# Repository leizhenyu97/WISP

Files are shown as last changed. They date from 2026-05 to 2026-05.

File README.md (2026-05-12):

# WISP (Wearable Imperceptible Sensing Platform)
<p align="center">
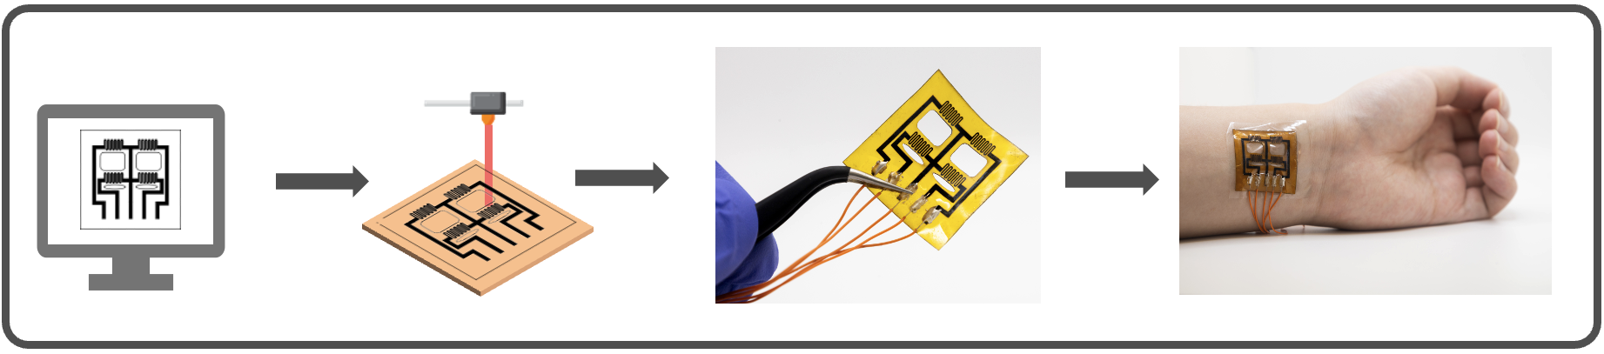
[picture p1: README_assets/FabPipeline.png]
FabPipeline
  
</p>

<p align="center">
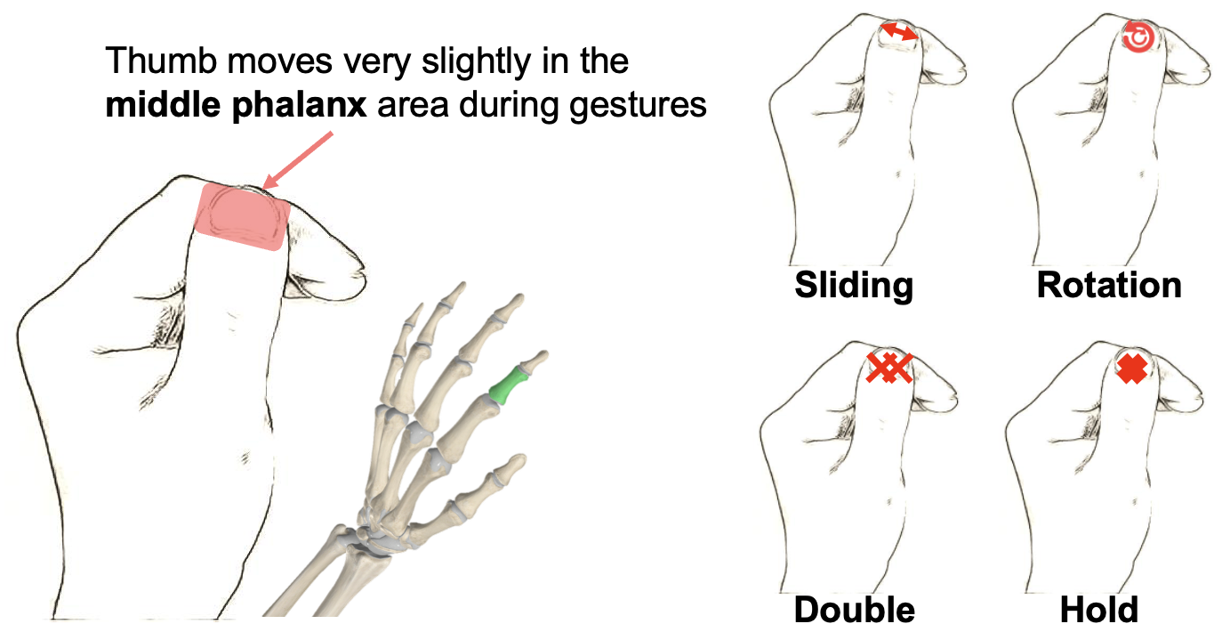
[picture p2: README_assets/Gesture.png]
Gesture
  
  <!-- <span style="display:inline-block; width:20px;"></span> -->
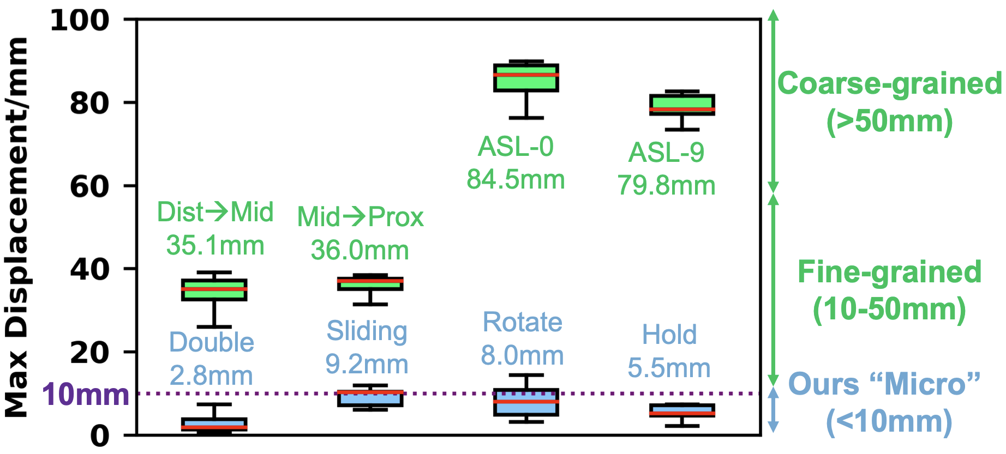
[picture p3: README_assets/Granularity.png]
Granularity
  
</p>

<h3 align="center">
  <a href="https://dl.acm.org/doi/10.1145/3774906.3800486">
    [ACM SenSys'26] WISP: Printable Graphene-Based Wearables for Force-Based Micro-Gesture Recognition
  </a>
</h3>

<p align="center">
  
</p>

***WISP*** provides a printable solution based on Laser-Induced Graphene (LIG) technology for **mm-scale micro-gesture recognition**, enabling discrete and unobtrusive interaction with smart devices. It translates tiny wrist deformations into piezoresistive changes, which are then digitized and streamed. In this repository, we open-source the sensing stack of WISP, including the sensor design, hardware, and firmware, featuring a **multi-channel** (2x2, extendable), **real-world-robust**, **high-sensitivity**, **low-noise** (100 uVpp), **low-power** (10 mW), and **compact** (4x4 cm) design. We hope this repository encourages further community involvement to improve and expand this area.

## Why WISP?
- Captures SOTA-level micro-gestures from extremely small force-based displacements, as demonstrated in multi-user, real-world studies and benchmarks.
- Provides a printable alternative to current gesture-recognition methods (e.g. EMG and accelerometers).
- Pushes LIG toward thinner substrates and helps bring it from the lab to the field.
- Offers an open-source multi-channel, low-noise, and low-power solution that can be extended to diverse piezoresistive sensors in a smartwatch-sized form factor.

## Get Started
### How It Works

<p align="left">
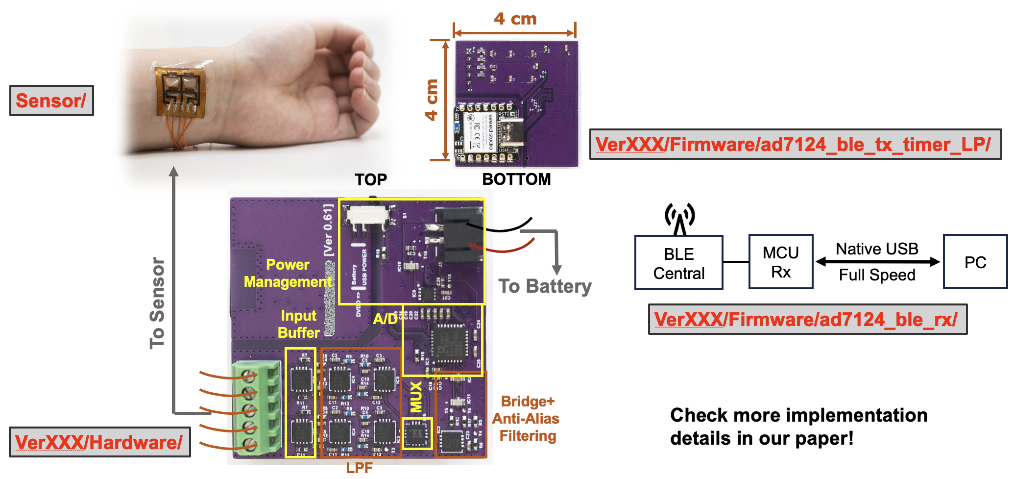
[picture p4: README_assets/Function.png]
Function
  
</p>

- [`Sensor/`](./Sensor/) includes our sensor-array design pattern for laser cutting on 25-um Polyimide (PI).
- Sensor post-processing improves robustness, signal decoupling, and connectivity (see the paper for details).
- [`Ver061/Hardware/`](./Ver061/Hardware/) includes the PCB design files and documentation. It performs analog signal conditioning, multiplexing, A/D conversion, and wireless data transmission to the host. Version 0.60 ([`Ver060/Hardware/`](./Ver060/Hardware/)) is also provided in the same format as a reference, featuring iron-solderability and better noise performance yet a double larger form factor. A comparison between Version 0.60 and 0.61 is provided in the [Version Comparison](#version-comparison) section below. You need to generate your own Gerber/NC drill files for fabrication.
- [`Ver061/Firmware/`](./Ver061/Firmware/) includes the firmware for nRF52840 modules (Seeed XIAO nRF52840). Both peripheral (Tx) and central (Rx) nodes are provided. Tx controls ADC/MUX/BLE timing and configuration, reads the measurements via high-speed SPI, and then packs and sends the data to Rx over BLE. A PC host can read the measurements in real time through USB. The firmware is designed to be compatible with Arduino. As with the hardware, the firmware for Ver 0.60 ([`Ver060/Firmware/`](./Ver060/Firmware/)) is also provided in the same format.

We worked hard to clean up and refactor the design and codebase, trying to make everything as simple as possible to follow. All implementations have been verified and tested by human experts on real devices. We hope this repository is useful to the community.

</details>

<details>
<summary><strong>Directory Structure</strong></summary>

```
.
├── .gitignore            
├── LICENSE                                     # MIT license                          
├── License_Driver                              # License files of the external libraries used in this repo
│   ├── LICENSE_ADAFRUIT_MIT.txt
│   └── LICENSE_ADI_BSD.txt
├── README_assets
│   ├── FabPipeline.png
│   ├── Function.png
│   ├── Gesture.png
│   └── Granularity.png
├── README.md                                    
├── Sensor
│   └── 2x2-array.pdf                            # 2×2 sensor array design reference.
├── Ver060
│   ├── Firmware
│   │   ├── ad7124_ble_rx
│   │   │   └── ad7124_ble_rx.ino                # BLE receiver sketch that forwards incoming data to USB serial.
│   │   └── ad7124_ble_tx_timer_LP
│   │       ├── ad7124_ble_tx_timer_LP.ino       # Main BLE transmitter sketch for timed sensing and packet streaming.
│   │       ├── ad7124_regs.c                    # AD7124 default register values used at startup.
│   │       ├── ad7124_regs.h                    # AD7124 register table declaration.
│   │       ├── AD7124.cpp                       # Low-level AD7124 SPI driver implementation.
│   │       ├── AD7124.h                         # Low-level AD7124 driver declarations and macros.
│   │       ├── adg726.cpp                       # External analog mux control for the Ver0.60 hardware path.
│   │       ├── adg726.h                         # External analog mux control declarations for Ver0.60.
│   │       ├── CN0391.cpp                       # Sensor readout helper implementation built on the AD7124 path.
│   │       ├── CN0391.h                         # Sensor readout helper declarations.
│   │       ├── Communication.cpp                # Minimal SPI transfer helpers shared by the firmware.
│   │       ├── Communication.h                  # Shared SPI helper declarations and pin definitions.
│   │       └── PROGMEM_readAnything.h           # Small utility templates for reading typed data from program memory.
│   └── Hardware
│       ├── ver060.Annotation                    # Hardware annotation metadata for Ver0.60.
│       ├── ver060.PDF                           # Exported hardware reference document for Ver0.60.
│       ├── ver060.PcbDoc                        # PCB layout source for Ver0.60.
│       ├── ver060.stackup                       # PCB layer stack definition for Ver0.60.
│       ├── ver060_ADC.SchDoc                    # ADC section schematic for Ver0.60.
│       ├── ver060_LPF.SchDoc                    # Low-pass filter schematic for Ver0.60.
│       ├── ver060_MCU.SchDoc                    # MCU section schematic for Ver0.60.
│       ├── ver060_Overview.SchDoc               # Top-level schematic overview for Ver0.60.
│       ├── ver060_Power.SchDoc                  # Power section schematic for Ver0.60.
│       └── ver060_SignalAnalog.SchDoc           # Analog signal path schematic for Ver0.60.
└── Ver061
    ├── Firmware
    │   ├── ad7124_ble_rx
    │   │   └── ad7124_ble_rx.ino                # BLE receiver sketch that forwards incoming data to USB serial.
    │   └── ad7124_ble_tx_timer_LP
    │       ├── ad7124_ble_tx_timer_LP.ino       # Main BLE transmitter sketch for timed sensing and packet streaming.
    │       ├── ad7124_regs.c                    # AD7124 default register values used at startup.
    │       ├── ad7124_regs.h                    # AD7124 register table declaration.
    │       ├── AD7124.cpp                       # Low-level AD7124 SPI driver implementation.
    │       ├── AD7124.h                         # Low-level AD7124 driver declarations and macros.
    │       ├── adg726.cpp                       # Alternative analog mux control implementation kept alongside Ver0.61.
    │       ├── adg726.h                         # Alternative analog mux control declarations kept alongside Ver0.61.
    │       ├── CN0391.cpp                       # Sensor readout helper implementation built on the AD7124 path.
    │       ├── CN0391.h                         # Sensor readout helper declarations.
    │       ├── Communication.cpp                # Minimal SPI transfer helpers shared by the firmware.
    │       ├── Communication.h                  # Shared SPI helper declarations and pin definitions.
    │       ├── max4734.cpp                      # Active analog switch control for the Ver0.61 hardware path.
    │       ├── max4734.h                        # Active analog switch control declarations for Ver0.61.
    │       └── PROGMEM_readAnything.h           # Small utility templates for reading typed data from program memory.
    └── Hardware
        ├── ver061.Annotation                    # Hardware annotation metadata for Ver0.61.
        ├── ver061.PDF                           # Exported hardware reference document for Ver0.61.
        ├── ver061.PcbDoc                        # PCB layout source for Ver0.61.
        ├── ver061.stackup                       # PCB layer stack definition for Ver0.61.
        ├── ver061_ADC.SchDoc                    # ADC section schematic for Ver0.61.
        ├── ver061_LPF.SchDoc                    # Low-pass filter schematic for Ver0.61.
        ├── ver061_MCU.SchDoc                    # MCU section schematic for Ver0.61.
        ├── ver061_Overview.SchDoc               # Top-level schematic overview for Ver0.61.
        ├── ver061_Power.SchDoc                  # Power section schematic for Ver0.61.
        └── ver061_SignalAnalog.SchDoc           # Analog signal path schematic for Ver0.61.

```
</details>

### Setup
- macOS 15.6 on a 14-inch MacBook Pro with M1 Pro
- Arduino 2.3
- Seeed nRF52 Boards library 1.1.4 (BLE SoftDevice S140 7.3.0)
- Altium Designer 26
- Python >= 3.10
- 0.05% precision resistors for critical locations
- The DVDD port of the MCU can be connected to either USB or battery power through a switch. During firmware upload or data logging via USB, connect DVDD to USB power. During normal data logging via BLE, connect DVDD to the battery. Connecting DVDD to the battery while USB is also connected can be dangerous or noisy without protection circuits.

### Version Comparison
<table border="1" width="75%">
  <tr>
    <td align="left" width="20%">
    </td>
    <td align="center" width="40%">
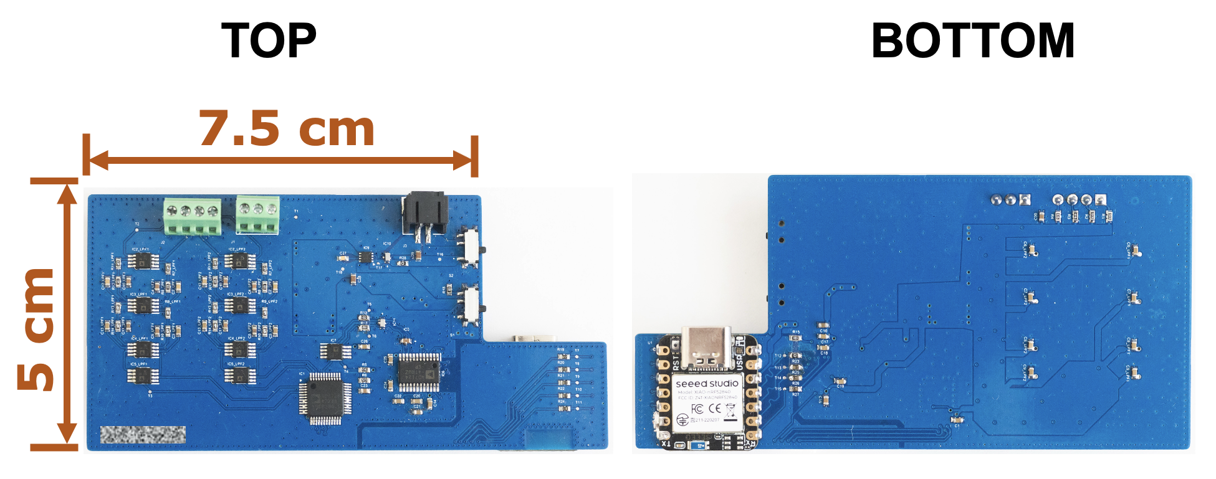
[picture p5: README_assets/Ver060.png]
        <br>
        <strong>Ver0.60</strong><br>
    </td>
    <td align="center" width="40%">
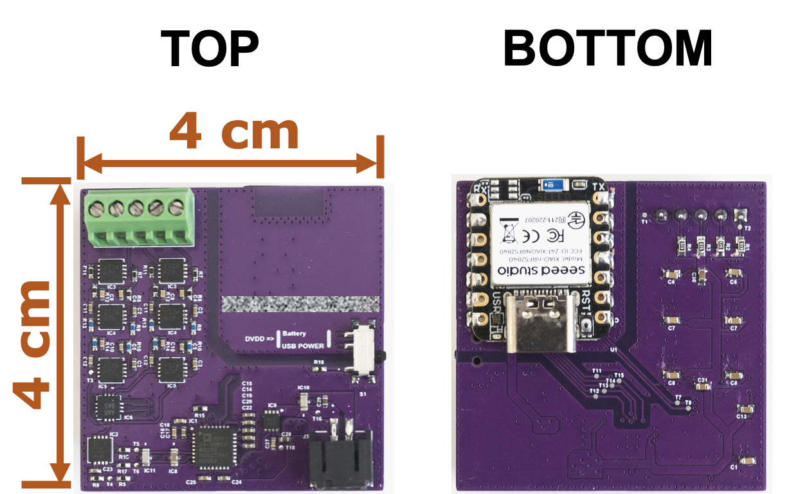
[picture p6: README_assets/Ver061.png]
        <br>
        <strong>Ver0.61</strong><br>
    </td>
  </tr>

  <tr>
    <td align="left" width="20%">
        <strong>Noise Range <sup>[1]</sup></strong><br>
    </td>
    <td align="center" width="40%">
        50-200 uVpp
    </td>
    <td align="center" width="40%">
        100-350 uVpp
    </td>
  </tr>

  <tr>
    <td align="left" width="20%">
        <strong>Iron-Solderability</strong><br>
    </td>
    <td align="center" width="40%">
        Yes
    </td>
    <td align="center" width="40%">
        Possible but not easy (space is limited)
    </td>
  </tr>

  <tr>
    <td align="left" width="20%">
        <strong>Dimension</strong><br>
    </td>
    <td align="center" width="40%">
        5 cm x 7.5 cm (mostly 0603 components)
    </td>
    <td align="center" width="40%">
        4 cm x 4 cm (mostly 0402 components)
    </td>
  </tr>
</table>
<sub>[1] The noise performance is measured end-to-end, which can be influenced by several elements: sensor fabrication, environment noise/interference (powerline, RFI, etc), human body posture/orientation, sensor attachment condition, length and material of wires, soldering quality, component quality/precision, and so on.</sub>

## Future Improvement
### Towards Version 0.62
Ver 0.62 targets noise performance as good as Ver 0.60 (50 uVpp) with a form factor as small as Ver 0.61 (4 cm x 4 cm). The main improvements will be in PCB layout and firmware timing. This includes, but is not limited to:
- More clearance between the board edge and the analog components.
- Reshaping the copper pour and removing unnecessary regions.
- Improving via usage for grounding, return paths, and fencing.
- Stricter star-connected power routing.
- Adding small resistors between the two X2Y capacitors to dampen anti-resonance.
- Better power decoupling.
- More precise MCU timing using timer-based interrupts (the timer currently somehow conflicts with the BLE, so it is disabled).

If you have any thoughts on how to improve performance, please do not hesitate to share them with us!

## Citation
If you use this repository, we appreciate your starring this repo and citing the paper below

```
Zhenyu Lei, Xiaomeng Liu, Quan Zhang, VP Nguyen, Jun Yao, and Deepak Ganesan. 2026. WISP: Printable Graphene-Based Wearables for Force-Based Micro-Gesture Recognition. In Proceedings of the 2026 ACM/IEEE International Conference on Embedded Artificial Intelligence and Sensing Systems (SenSys '26). Association for Computing Machinery, New York, NY, USA, 531–544. https://doi.org/10.1145/3774906.3800486
```

## License
MIT © Zhenyu Lei (zhenyulei@umass.edu)

## Acknowledgements
WISP is built on top of the open-source drivers from Analog Device Inc. and Adafruit Inc. The original licenses and copyright notices for these drivers are preserved in [`License_Driver/`](./License_Driver/).

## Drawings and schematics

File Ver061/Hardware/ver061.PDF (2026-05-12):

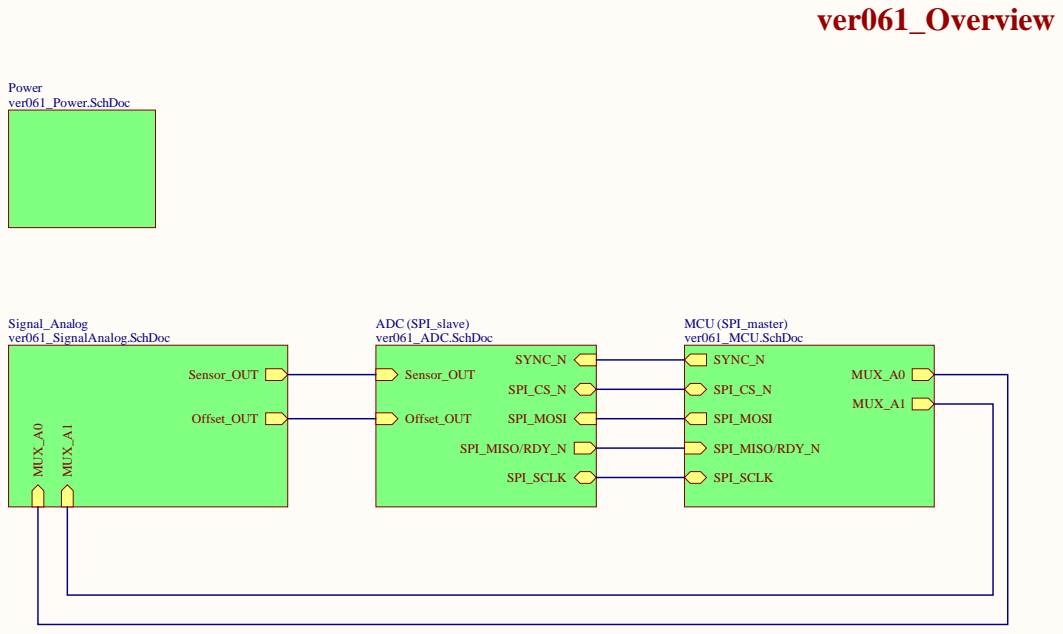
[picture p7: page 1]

SPI_CS_N | SPI_CS_N MUX_A1

Offset_OUT | Offset_OUT SPI_MOSI SPI_MISO/RDY_N SPI_SCLK | SPI_MOSI SPI_MISO/RDY_N SPI_SCLK

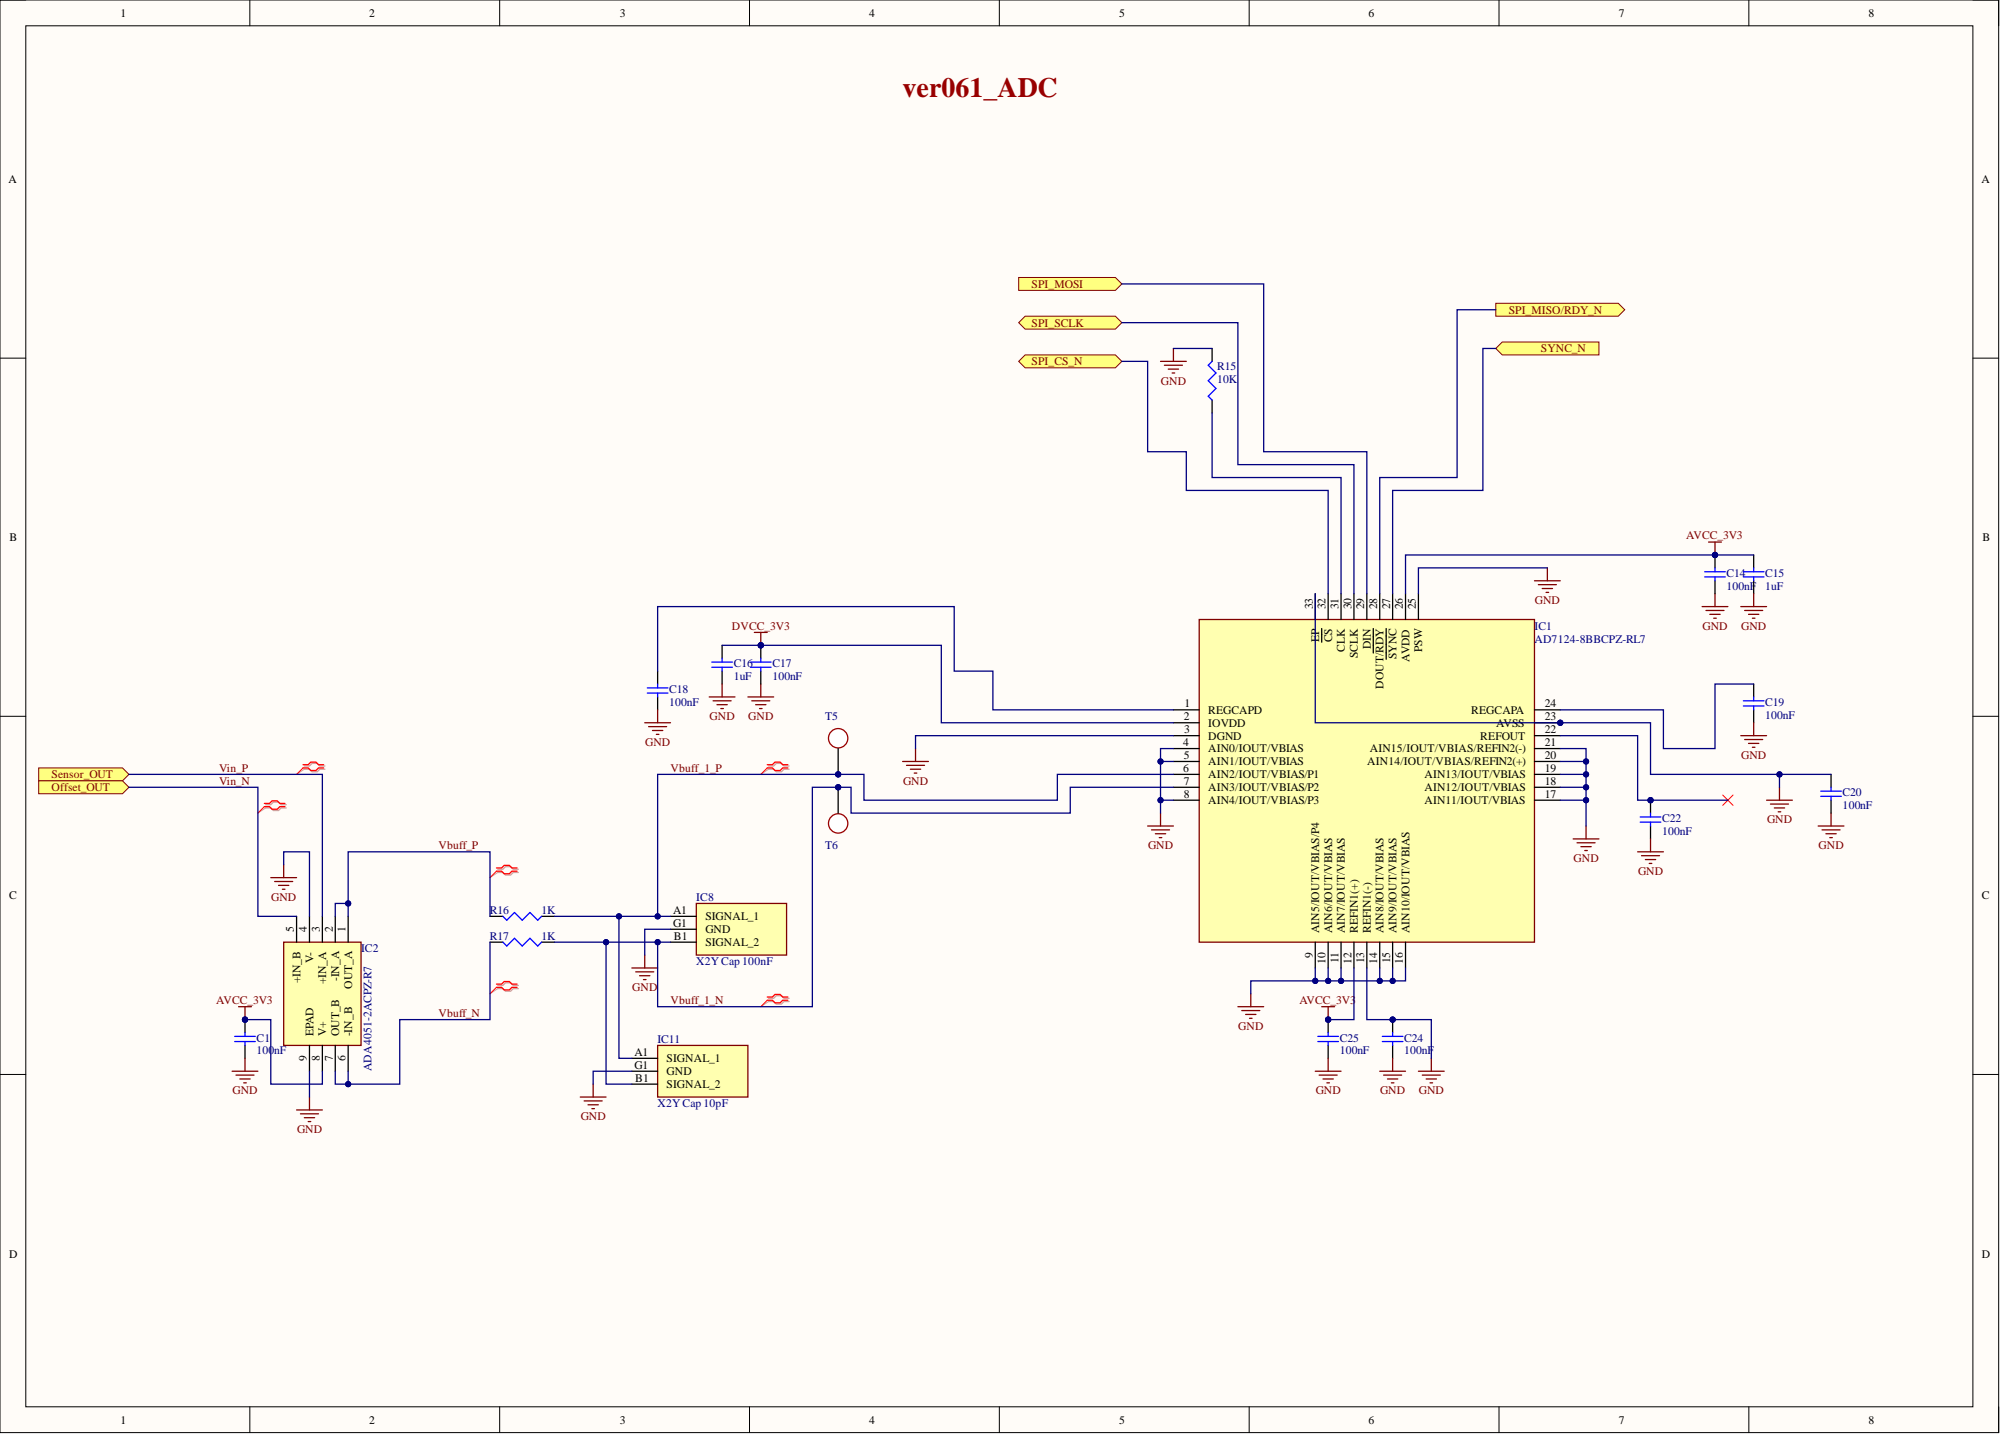
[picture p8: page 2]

D G N D AIN 0 /IO U T / V B IA S AIN 1 /IO U T / V B IA S AIN 2 /IO U T / VBI A S /P AIN 3 /IO U T / VBI A S /P AIN 4 /IO U T / VBI A S /P | RE GCA PA
2 | 2 3

4 | | 2 1
5 | | 2 0
6 | | 1 9

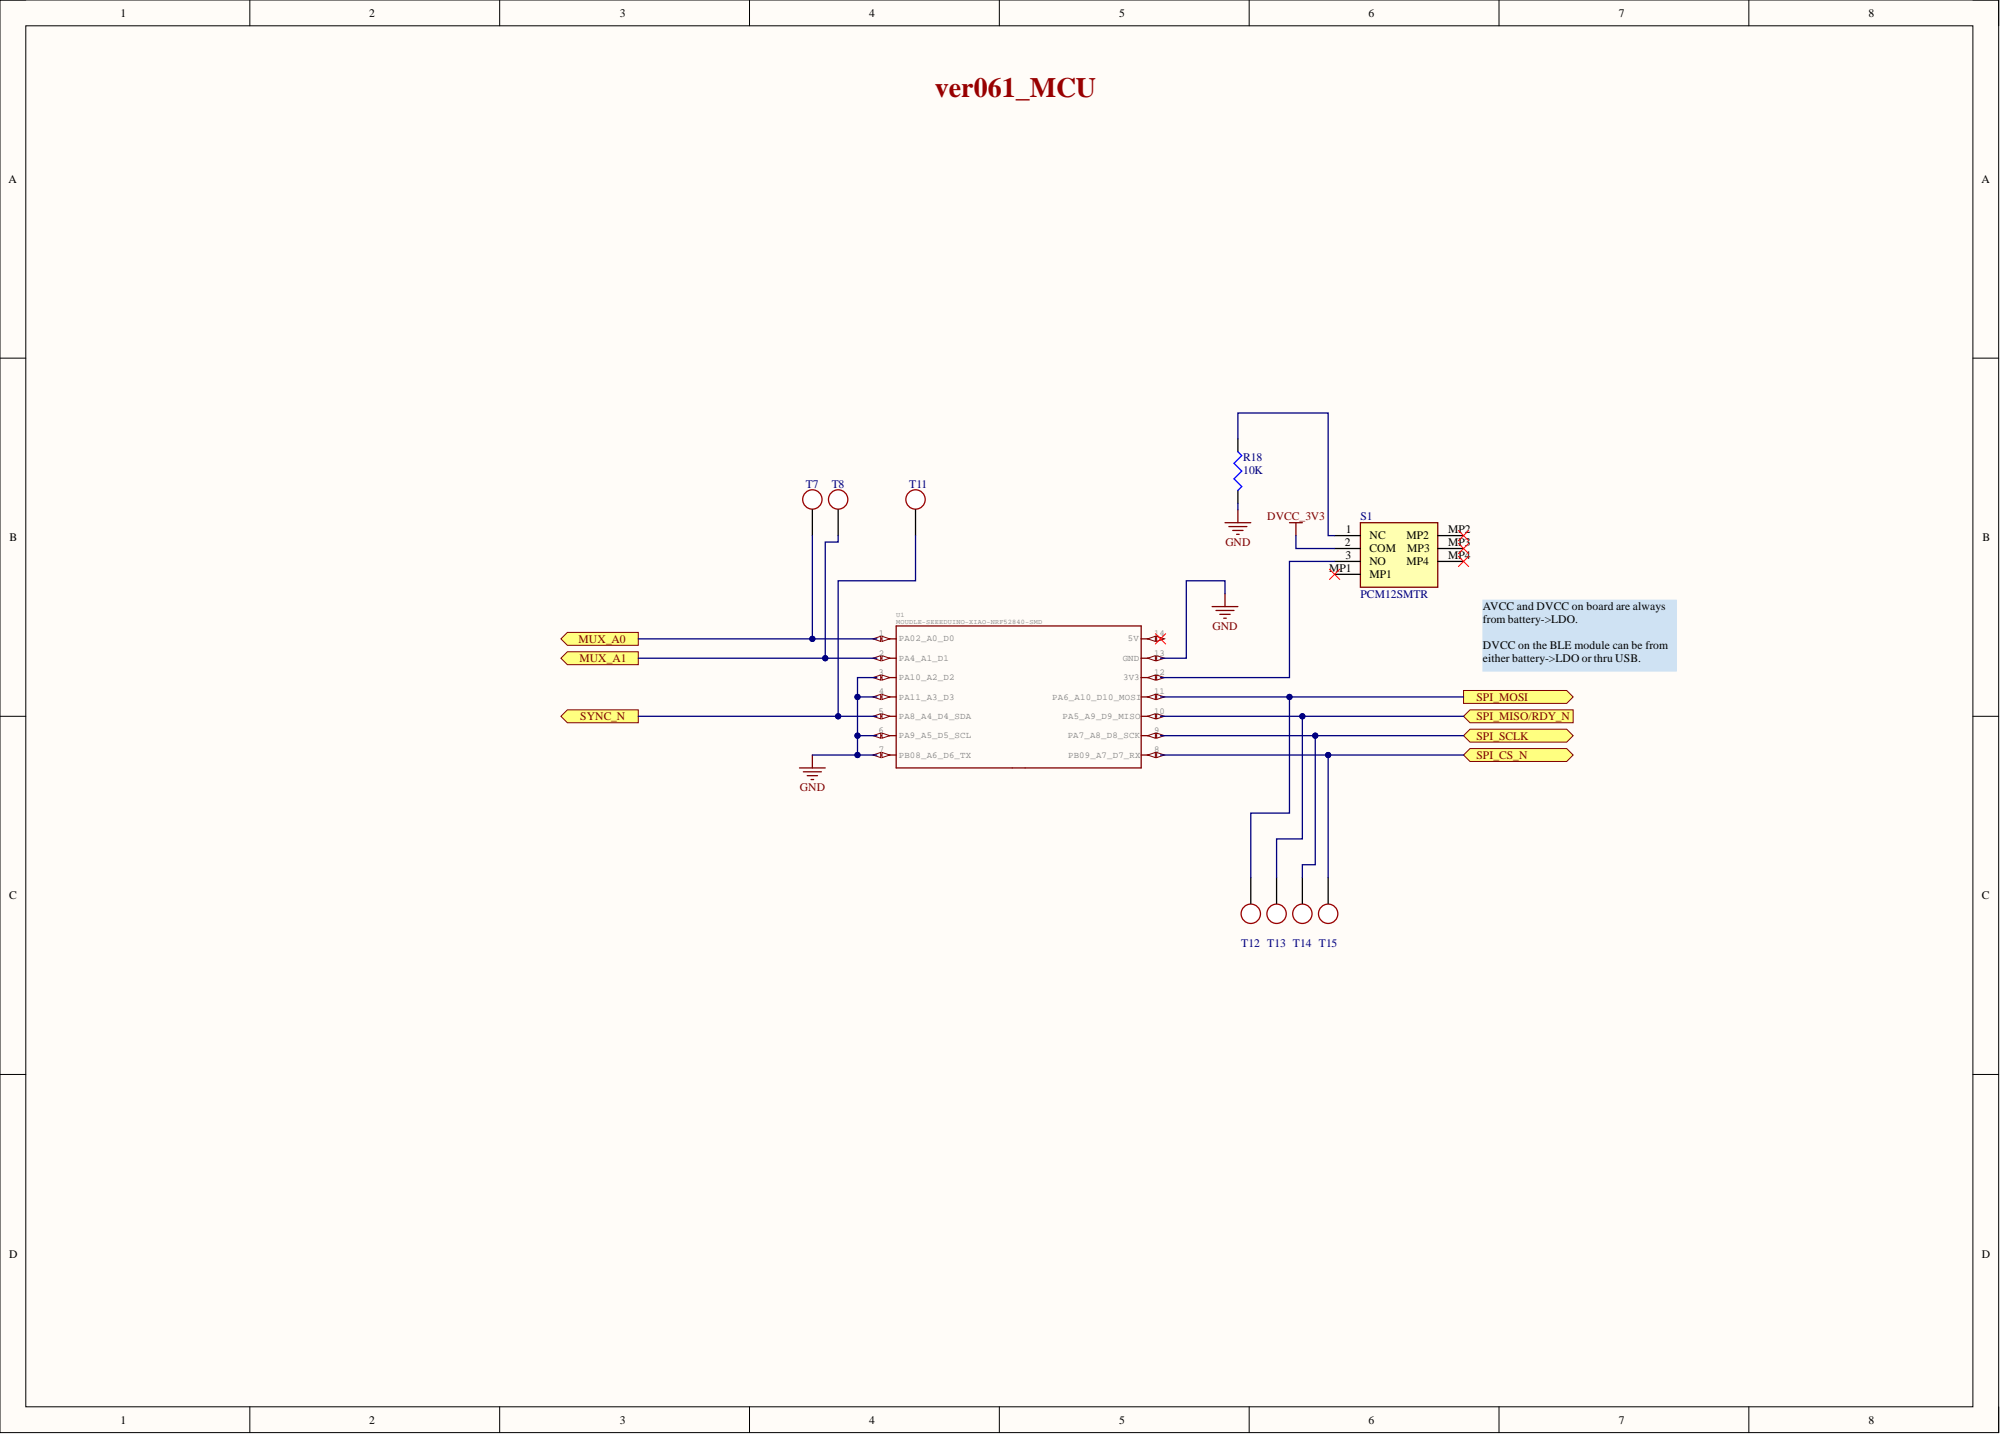
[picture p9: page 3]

AVCC and DVCC on board are always
from battery->LDO.

DVCC on the BLE module can be from
either battery->LDO or thru USB.

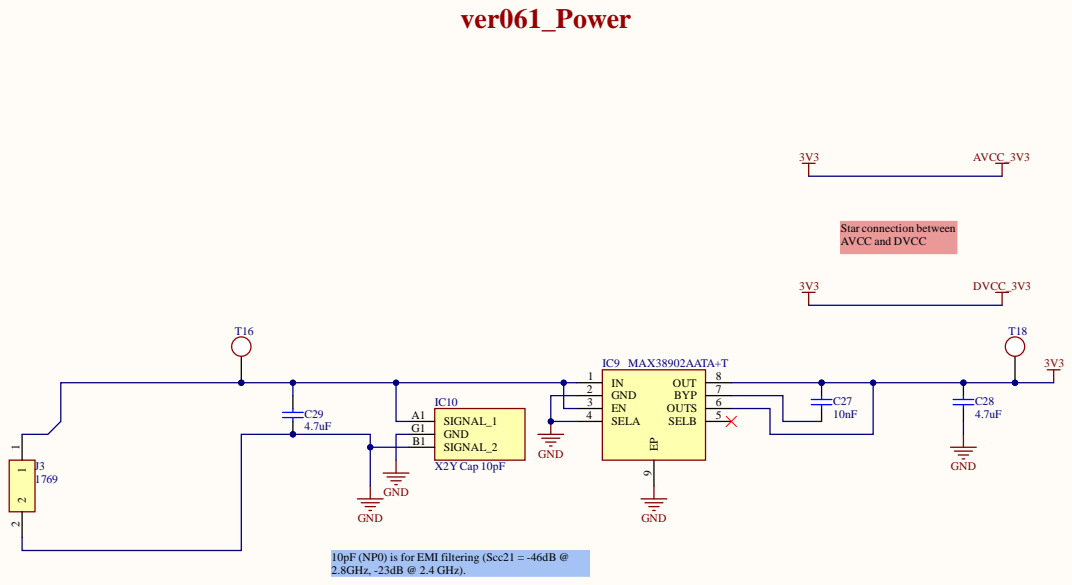
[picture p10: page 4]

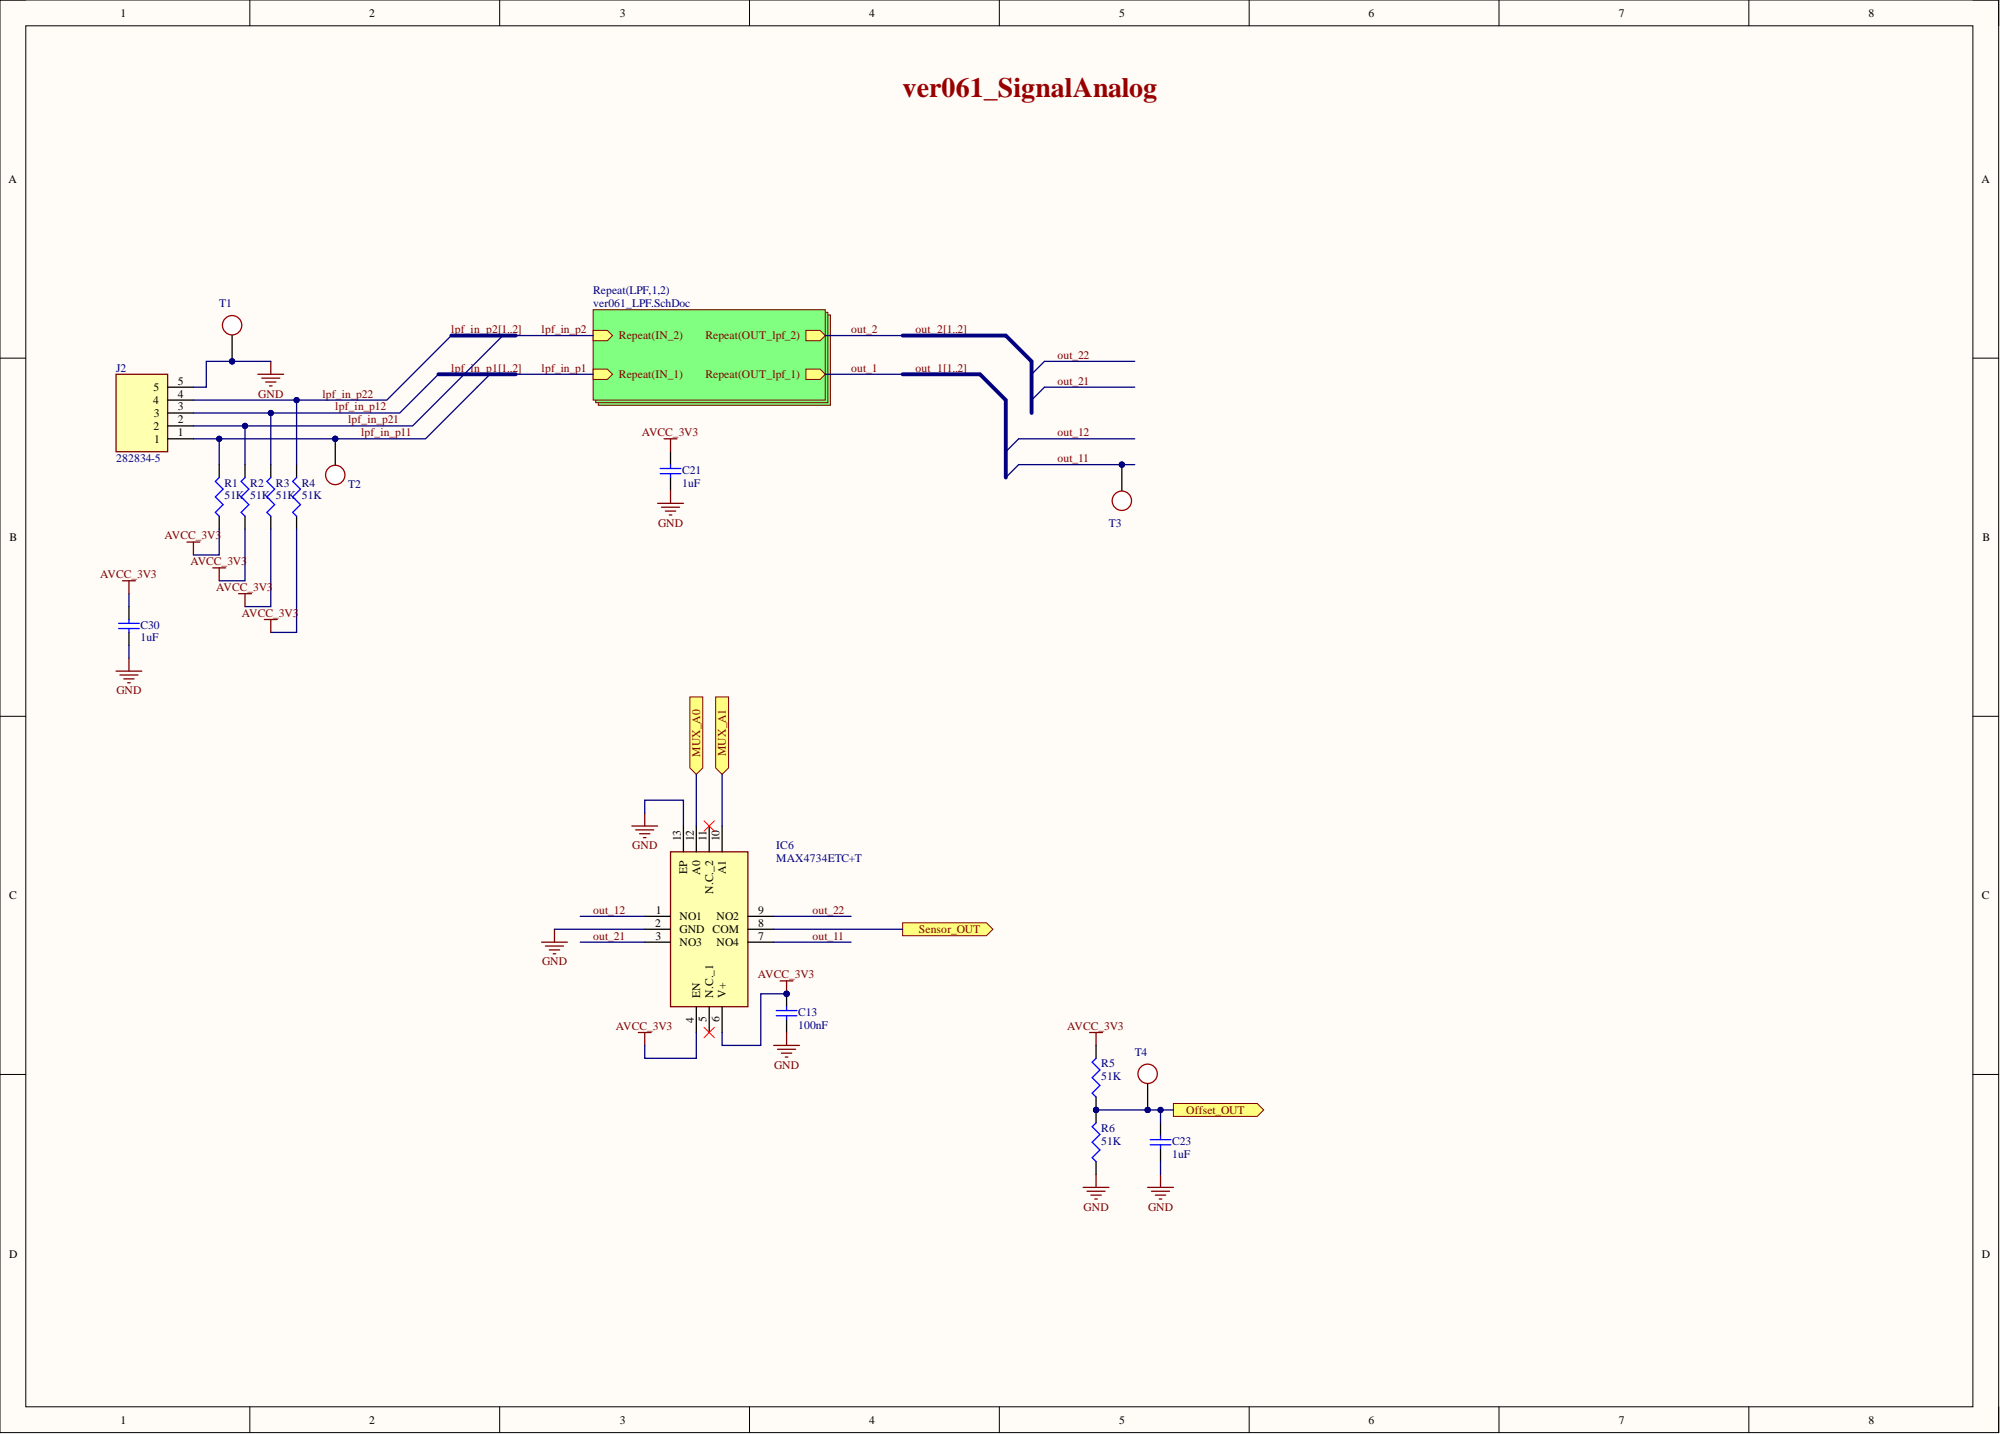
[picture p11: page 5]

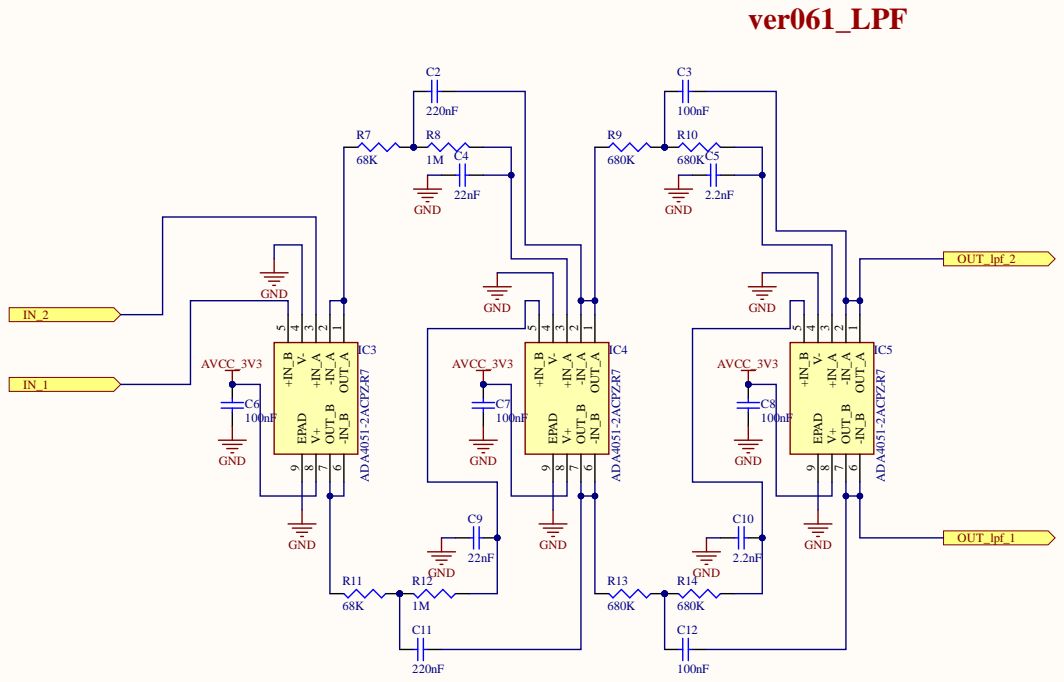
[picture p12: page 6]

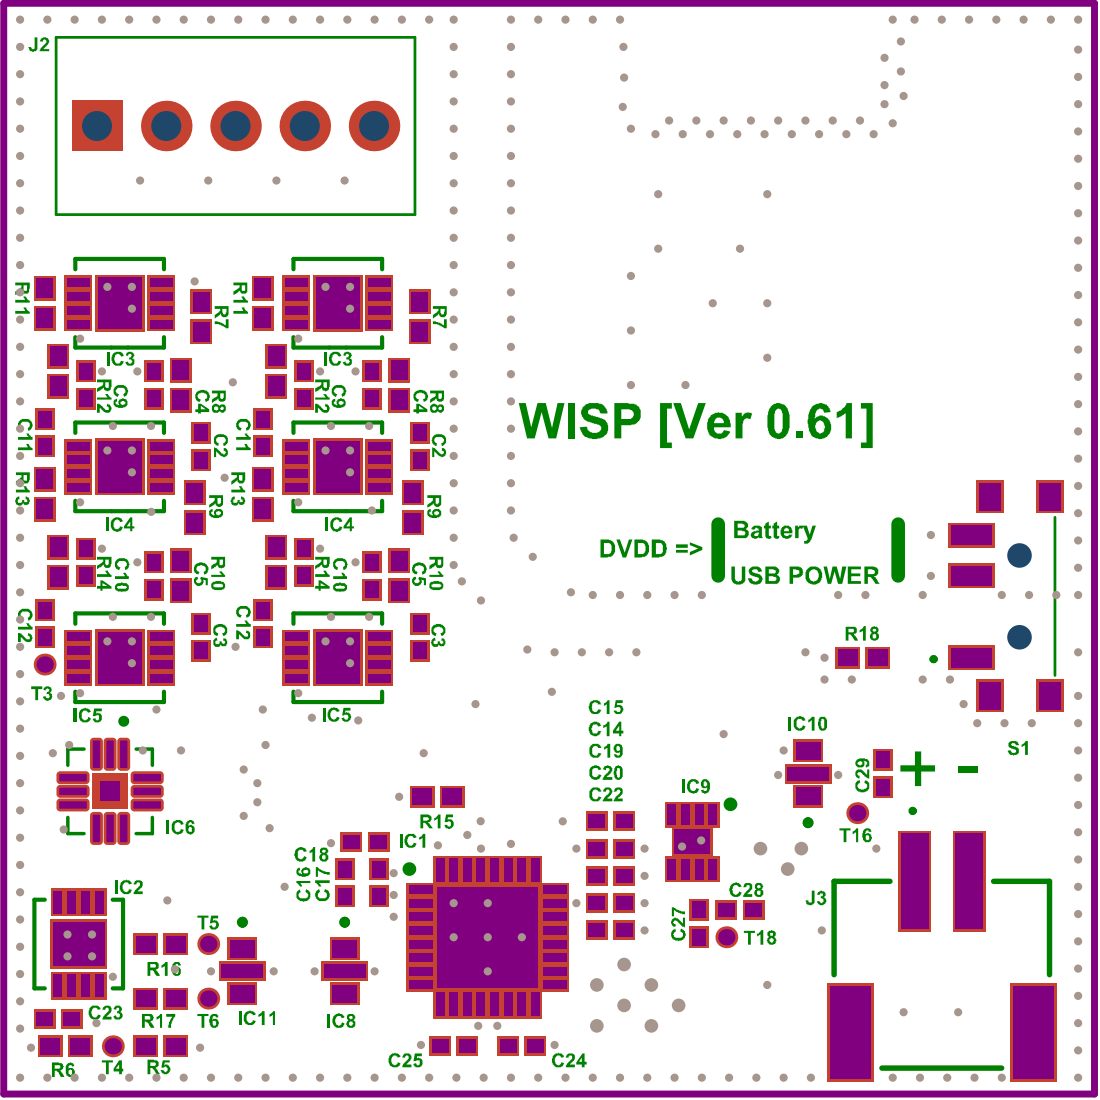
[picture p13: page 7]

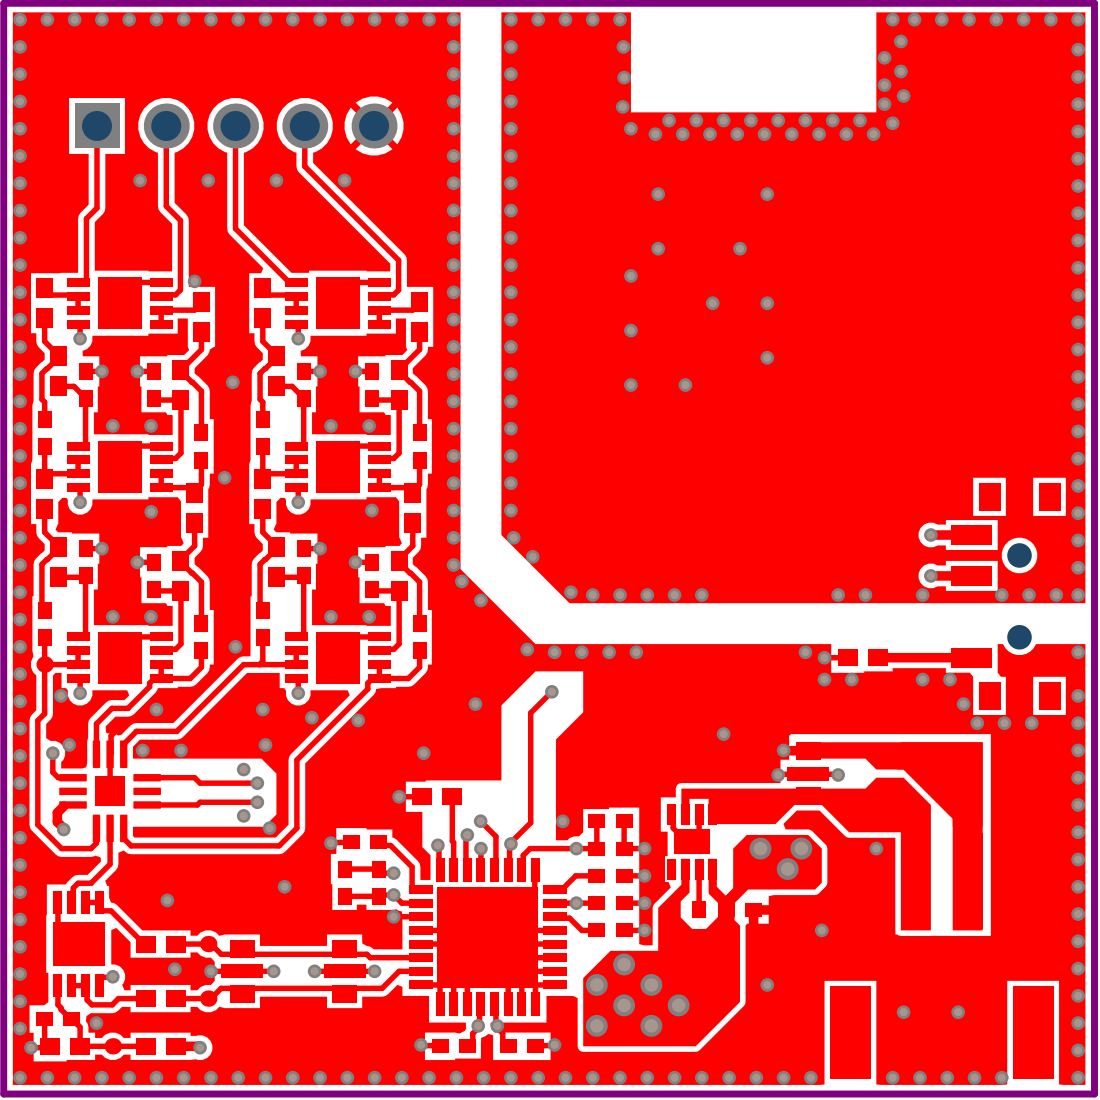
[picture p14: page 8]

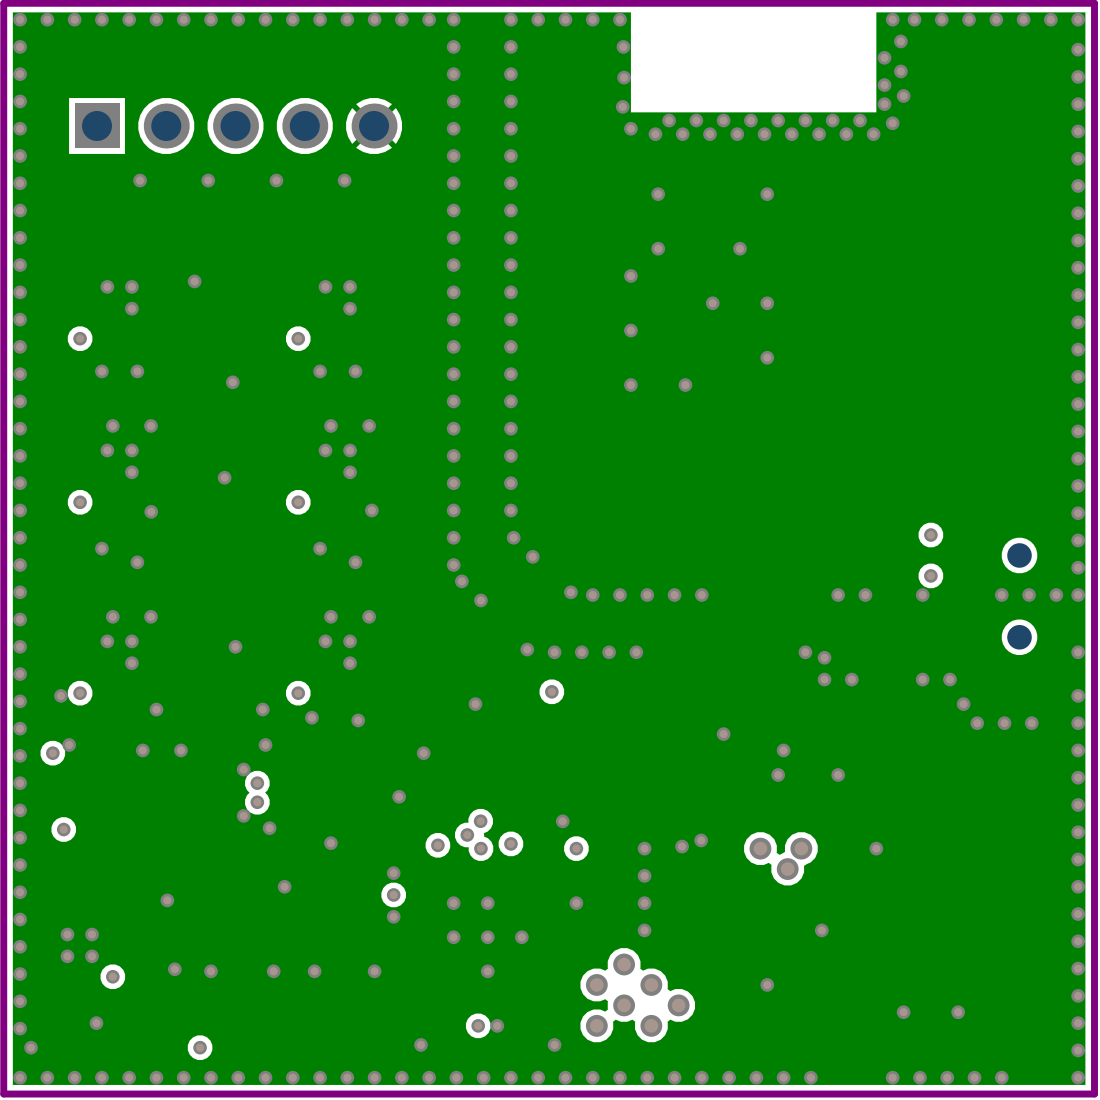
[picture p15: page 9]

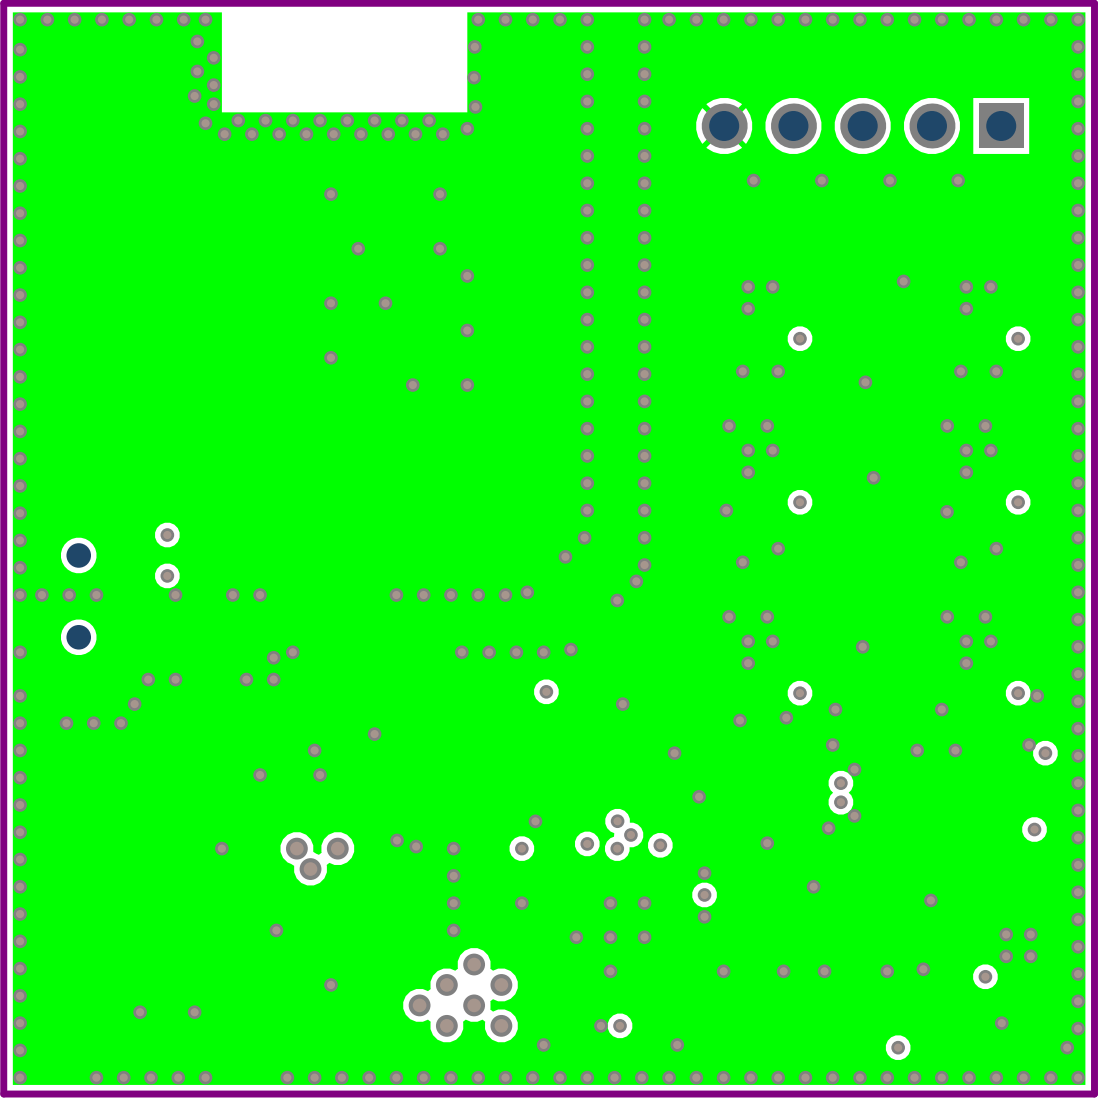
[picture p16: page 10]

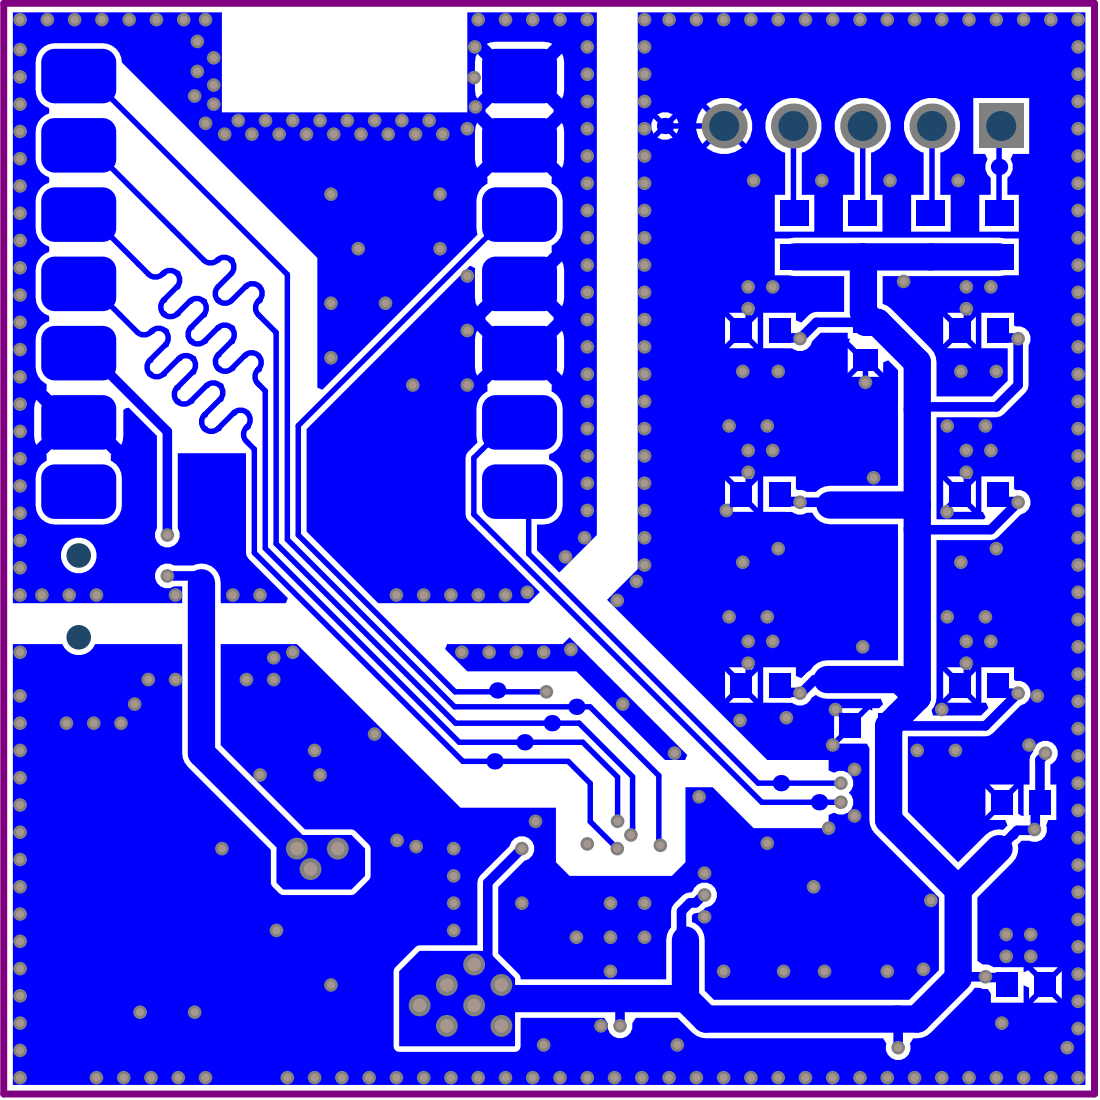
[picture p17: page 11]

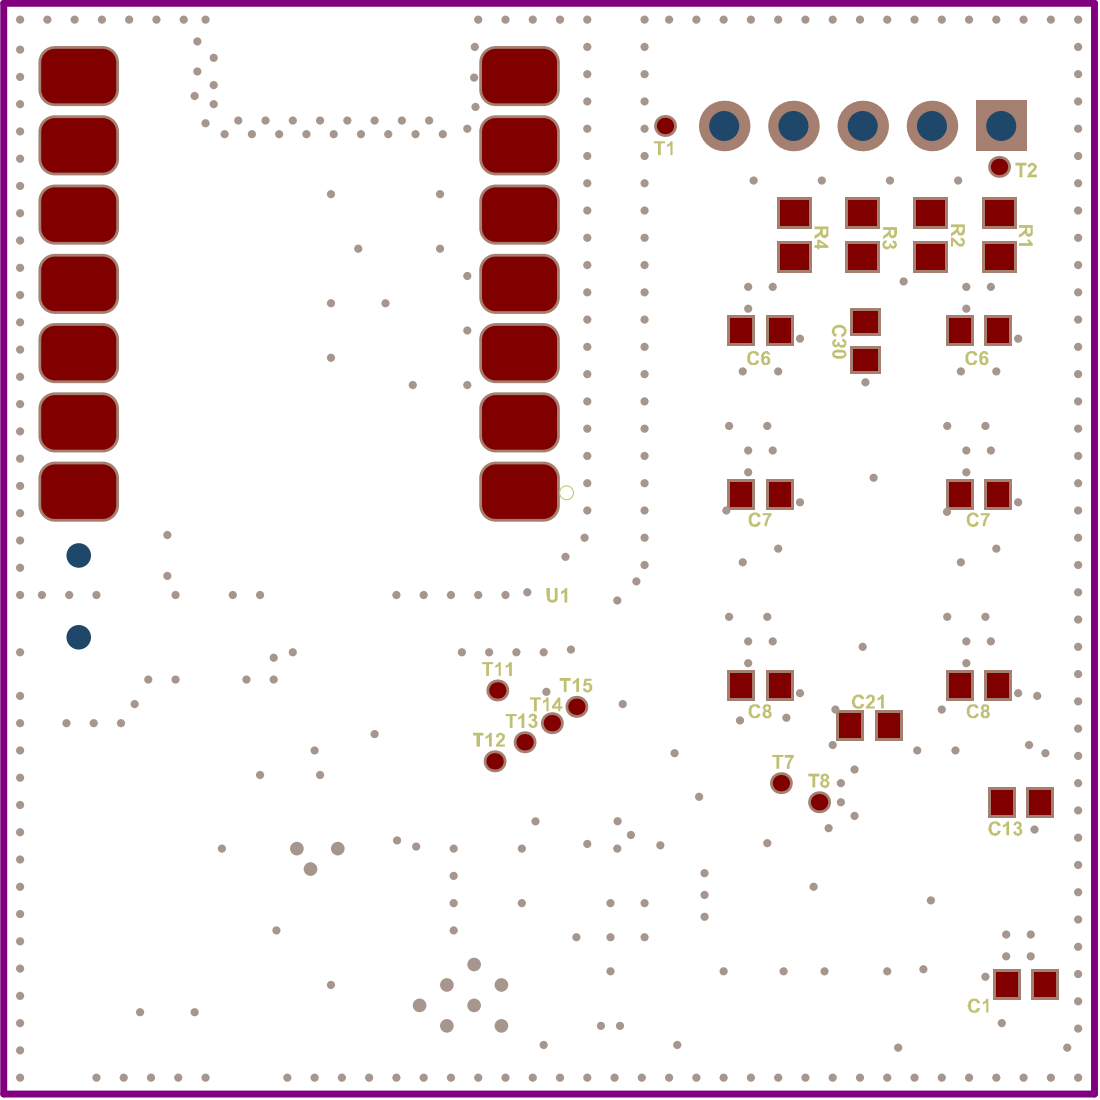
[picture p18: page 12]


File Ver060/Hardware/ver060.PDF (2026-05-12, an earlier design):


SPI_CS_N | SPI_CS_N MUX_A1

Offset_OUT | Offset_OUT SPI_MOSI | SPI_MOSI MUX_A2

SPI_MISO/RDY_N | SPI_MISO/RDY_N MUX_A3

SPI_SCLK | SPI_SCLK


out_21 | S11A 2 S10A 3 | 35

out_11 | S9A 4 S8A 5 | 33

S7A 6 | 31
S6A 7 | 30
S5A 8 | 29
S4A 9 | 28
S3A 10 | 27
S2A 11 | 26



2 | | 2 3
3 | | 2 2
4 | | 2 1
5 | | 2 0
6 | | 1 9

8 | | 1 7
9 | | 1 6


AVCC and DVCC on board are always
from battery->LDO.

DVCC on the BLE module can be from
either battery->LDO or thru USB.








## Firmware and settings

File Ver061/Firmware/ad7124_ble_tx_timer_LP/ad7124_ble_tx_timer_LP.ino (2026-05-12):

// BLE-triggered AD7124 acquisition loop: rotates an external MAX4734 mux across
// four inputs, formats each full scan as ASCII, and batches scans for BLE UART transmission.

// These define's must be placed at the beginning before #include "NRF52TimerInterrupt.h"
// _TIMERINTERRUPT_LOGLEVEL_ from 0 to 4
// Don't define _TIMERINTERRUPT_LOGLEVEL_ > 0. Only for special ISR debugging only. Can hang the system.
// Don't define TIMER_INTERRUPT_DEBUG > 2. Only for special ISR debugging only. Can hang the system.
#define TIMER_INTERRUPT_DEBUG         0
#define _TIMERINTERRUPT_LOGLEVEL_     0

#include "Communication.h"
#include "AD7124.h"
#include "AD7124_regs.h"
#include <SPI.h>
#include "CN0391.h"
#include "max4734.h"
#include "Arduino.h"
#include <bluefruit.h>
#include "Adafruit_TinyUSB.h"

// To be included only in main(), .ino with setup() to avoid `Multiple Definitions` Linker Error
#include "NRF52TimerInterrupt.h"
#include "NRF52_ISR_Timer.h"


# define CHANNELNUM 4
# define SAMPLECOMBINE 5

const uint8_t ADC_ch_fix = 0;                    // Fixed AD7124 logical channel used while the external mux selects the physical input.
const uint8_t ch_list[CHANNELNUM] = {0,1,2,3};  // External mux channel order for one full scan.
const uint8_t ch_idx_init = 0;                   // Scan start index used to detect frame boundaries.
volatile uint8_t ch_idx = ch_idx_init;           // Current mux position shared with the acquisition loop.
volatile uint8_t SAMPLECOMBINE_cnt = 0;          // Counts completed full scans before one BLE write.
char ble_buffer[244] = {0};                      // Aggregated ASCII BLE payload buffer.
char sample_buffer[CHANNELNUM*(8+1)] = {0};      // One full scan of fixed-width channel samples plus separators.
volatile int value;                              // Latest raw ADC code returned by the current conversion.
char *buff_pnt = sample_buffer;                  // Write cursor into the current scan buffer.
char *ble_buff_pnt = ble_buffer;                 // Write cursor into the aggregated BLE buffer.
volatile bool DataValid = true;                  // Drops the current scan if any channel read returns an invalid sentinel.
volatile bool ConfigComplete = false;            // Blocks loop activity until the connect callback finishes hardware setup.
volatile bool TimeUp = true;                     // Sampling tick flag raised asynchronously by the timer path.

volatile bool SerialSwitch = false;   // Only for printing log output, not for telemetry transmission.

BLEUart bleuart;                                 // BLE UART service used for telemetry transmission.

NRF52Timer ITimer0(NRF_TIMER_4);                 // Hardware timer used to service the ISR timer scheduler. NOTE: We do not use any timer in this implementation. Ignore all locations where it appears.

// Init NRF52_ISR_Timer
// Each NRF52_ISR_Timer can service 16 different ISR-based timers
NRF52_ISR_Timer ISR_Timer;                       // ISR-safe software timer dispatcher.

SPISettings MyFastSPI = SPISettings(F_CPU / SPI_CLOCK_DIV2, MSBFIRST, SPI_MODE3);  // SPI settings required by the AD7124 path.


/**
 * Services the ISR timer dispatcher from the hardware timer callback.
 *
 * @return None.
 */
void TimerHandler0(){
  ISR_Timer.run();
}

/**
 * Raises the sampling-ready flag consumed by the main acquisition loop.
 *
 * @return None.
 */
void TimeInterrupt_service()
{
  TimeUp = true;
}


/**
 * Initializes GPIO, SPI, BLE UART, and advertising for the streaming firmware path.
 *
 * @return None.
 */
void setup() {
  // These delays preserve the established CS/SYNC bring-up timing for the front-end hardware.
  pinMode(CS_PIN, OUTPUT);  // pinmode change must have a delay at least 100us. 10us is not enough!
  delayMicroseconds(100);
  digitalWrite(CS_PIN, HIGH);
  delayMicroseconds(100);
  pinMode(SYNC_PIN, OUTPUT);
  digitalWrite(SYNC_PIN, HIGH);
  delayMicroseconds(1000);  // CS_pin selection must have a delay at least 1ms. 100us is not enough!

  memset(ble_buffer, 0, 244);
  memset(sample_buffer, 0, CHANNELNUM*(8+1));

  if (SerialSwitch){
    Serial.begin(115200);
    while ( !Serial ) delay(10);   // for nrf52840 with native usb

    Serial.println("Peripheral BLEUART Tx");
    Serial.println("-----------------------------------\n");
  }
  
  // Prime the SPI peripheral once during boot so later transactions begin from a known state.
  SPI.begin();
  SPI.end();

  // Setup the BLE LED to be enabled on CONNECT
  // Note: This is actually the default behaviour, but provided
  // here in case you want to control this manually via PIN 19
  Bluefruit.autoConnLed(false);

  // Config the peripheral connection with maximum bandwidth
  // more SRAM required by SoftDevice
  // Note: All config***() function must be called before begin()
  Bluefruit.configPrphBandwidth(BANDWIDTH_MAX);

  Bluefruit.begin();
  Bluefruit.setTxPower(0);    // Check bluefruit.h for supported values
  Bluefruit.Periph.setConnectCallback(connect_callback);
  Bluefruit.Periph.setDisconnectCallback(disconnect_callback);
  Bluefruit.Periph.setConnInterval(6, 12); // 7.5 - 15 ms

  // Configure and Start BLE Uart Service
  bleuart.begin();

  // Set up and start advertising
  startAdv();
}

/**
 * Configures the advertising and scan-response payload for the BLE UART service.
 *
 * @return None.
 */
void startAdv(void)
{
  Bluefruit.Advertising.addFlags(BLE_GAP_ADV_FLAGS_LE_ONLY_GENERAL_DISC_MODE);
  Bluefruit.Advertising.addTxPower();

  // Include bleuart 128-bit uuid
  Bluefruit.Advertising.addService(bleuart);

  // There is no room for Name in Advertising packet
  // Use Scan response for Name
  Bluefruit.ScanResponse.addName();
  
  /* Start Advertising
   * - Enable auto advertising if disconnected
   * - Interval:  fast mode = 20 ms, slow mode = 152.5 ms
   * - Timeout for fast mode is 30 seconds
   * - Start(timeout) with timeout = 0 will advertise forever (until connected)
   * 
   * For recommended advertising interval
   * https://developer.apple.com/library/content/qa/qa1931/_index.html
   */
  Bluefruit.Advertising.restartOnDisconnect(true);
  Bluefruit.Advertising.setInterval(32, 244);    // in unit of 0.625 ms
  Bluefruit.Advertising.setFastTimeout(30);      // number of seconds in fast mode
  Bluefruit.Advertising.start(0);                // 0 = Don't stop advertising after n seconds
}

/**
 * Negotiates the BLE link and brings up the mux/ADC path for streaming.
 *
 * @param conn_handle Active BLE connection handle supplied by Bluefruit.
 * @return None.
 */
void connect_callback(uint16_t conn_handle)
{
  BLEConnection* conn = Bluefruit.Connection(conn_handle);
  

  if (SerialSwitch){
    Serial.println("Connected");

    Serial.println(conn->getPHY());
    Serial.println(conn->getDataLength());
    Serial.println(conn->getMtu());
  }

  // Keep the BLE link-upgrade requests grouped before acquisition begins.
  conn->requestPHY();
  conn->requestDataLengthUpdate();
  conn->requestMtuExchange(247);

  // Let PHY / data-length / MTU negotiation settle before ADC traffic starts.
  delay(1000);

  
  if (SerialSwitch){
    Serial.println(conn->getPHY());
    Serial.println(conn->getDataLength());
    Serial.println(conn->getMtu());
  }
  

  // Start the SPI transaction before mux and ADC configuration so chip-select timing stays unchanged.
  SPI.beginTransaction(MyFastSPI);

  delayMicroseconds(100);

  max4734_init();
  max4734_SelectChannel(ch_list[ch_idx]);

	digitalWrite(CS_PIN, LOW);

  CN0391_init();
  CN0391_enable_channel(ADC_ch_fix);

  digitalWrite(CS_PIN, HIGH);
  SPI.end();

  // Interval in microsecs
  if (ITimer0.attachInterruptInterval(1000, TimerHandler0))
  {
    if (SerialSwitch){
      Serial.print(F("Starting  ITimer0 OK, millis() = "));
      Serial.println(millis());
    }
  }
  else{
    if (SerialSwitch){
      Serial.println(F("Can't set ITimer0. Select another freq. or timer"));
    }
  }
  ITimer0.stopTimer();

  ConfigComplete = true;  // This Connect Callback function is not blocked and of low interruption priority,
                          // and the program will enter the loop function before it's completed.
                          // This flag will make sure the loop function runs after all configurations are done.
}

/**
 * Handles disconnect events and blocks acquisition until the next setup pass.
 *
 * @param conn_handle Connection where this event happens.
 * @param reason BLE HCI status code describing the disconnect.
 * @return None.
 */
void disconnect_callback(uint16_t conn_handle, uint8_t reason)
{
  (void) conn_handle;
  (void) reason;

  if (SerialSwitch){
    Serial.println();
    Serial.print("Disconnected, reason = 0x");
    Serial.println(reason, HEX);
  }
  

  ConfigComplete=false;
}

/**
 * Performs one ADC acquisition step, assembles full scan frames, and flushes batches over BLE.
 *
 * @return None.
 */
void loop(){

  if (ConfigComplete){
    if (TimeUp){
      if (Bluefruit.connected()){
        SPI.beginTransaction(MyFastSPI);

        digitalWrite(CS_PIN, LOW);
        value = read_channel(ADC_ch_fix);
        if ((value == 0)||(value == 1)){
          DataValid = false;
        }

        uint8_t ch_idx_new = (ch_idx + 1) % CHANNELNUM;
        max4734_SelectChannel(ch_list[ch_idx_new]);
        
        // Preserve the mux settle delay before the next conversion is restarted on the new input.
        delayMicroseconds(10);
        start_channel_conv(ADC_ch_fix);

        digitalWrite(CS_PIN, HIGH);
        SPI.end();

        sprintf(buff_pnt, "%08d", value);
        buff_pnt += 8;
        sprintf(buff_pnt," ");
        buff_pnt += 1;

        if (ch_idx_new==ch_idx_init){  // Reaching the initial index marks the end of one full channel scan.
          if (DataValid){
            // Capture one timestamp per completed scan frame, not per channel sample.
            sprintf(ble_buff_pnt,"%010d",micros());
            ble_buff_pnt += 10;
            sprintf(ble_buff_pnt," ");
            ble_buff_pnt += 1;
            sprintf(ble_buff_pnt,sample_buffer);
            ble_buff_pnt += sizeof(sample_buffer);
            sprintf(ble_buff_pnt,"\n");
            ble_buff_pnt += 1;

            SAMPLECOMBINE_cnt = (SAMPLECOMBINE_cnt + 1) % SAMPLECOMBINE;
          }
          else{
            DataValid = true;
          }

          memset(sample_buffer, 0, CHANNELNUM*(8+1));
          buff_pnt = sample_buffer;
        }

        ch_idx = ch_idx_new;

        
        if (SAMPLECOMBINE_cnt==0){  // Flush only after SAMPLECOMBINE complete scan frames have been accumulated.
          bleuart.write(ble_buffer);
          memset(ble_buffer, 0, 244);
          ble_buff_pnt = ble_buffer;
        }
      }
    }
  }

  waitForEvent();  // Idle until the next BLE or timer-driven event wakes the CPU.

  delay(5);   // Yield between iterations without changing the acquisition sequence.
}

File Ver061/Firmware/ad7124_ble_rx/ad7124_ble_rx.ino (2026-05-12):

#include <bluefruit.h>
#include "Adafruit_TinyUSB.h"


BLEClientUart clientUart; // bleuart client

char ble_buffer[244] = {0};


void setup()
{
  memset(ble_buffer, 0, 244);

  Serial.begin(115200);
  while ( !Serial ) delay(10);   // for nrf52840 with native usb

  // Serial.println("Central BLEUART Rx");
  // Serial.println("-----------------------------------\n");


  // Setup the BLE LED to be enabled on CONNECT
  // Note: This is actually the default behaviour, but provided
  // here in case you want to control this manually via PIN 19
  Bluefruit.autoConnLed(true);

  // Config the connection with maximum bandwidth 
  // more SRAM required by SoftDevice
  // Note: All config***() function must be called before begin()
  Bluefruit.configCentralBandwidth(BANDWIDTH_MAX);  
  
  // Initialize Bluefruit with maximum connections as Peripheral = 0, Central = 1
  // SRAM usage required by SoftDevice will increase dramatically with number of connections
  Bluefruit.begin(0, 1);
  
  Bluefruit.setName("Bluefruit52 Central");

  // Init BLE Central Uart Serivce
  clientUart.begin();
  clientUart.setRxCallback(bleuart_rx_callback);  

  // Increase Blink rate to different from PrPh advertising mode
  Bluefruit.setConnLedInterval(250);

  // Callbacks for Central
  Bluefruit.Central.setConnectCallback(connect_callback);
  Bluefruit.Central.setDisconnectCallback(disconnect_callback);

  /* Start Central Scanning
   * - Enable auto scan if disconnected
   * - Interval = 100 ms, window = 80 ms
   * - Don't use active scan
   * - Start(timeout) with timeout = 0 will scan forever (until connected)
   */
  Bluefruit.Scanner.setRxCallback(scan_callback);
  Bluefruit.Scanner.restartOnDisconnect(true);
  Bluefruit.Scanner.setInterval(160, 80); // in unit of 0.625 ms
  Bluefruit.Scanner.useActiveScan(false);
  Bluefruit.Scanner.start(0);                   // // 0 = Don't stop scanning after n seconds
}

/**
 * Callback invoked when scanner pick up an advertising data
 * @param report Structural advertising data
 */
void scan_callback(ble_gap_evt_adv_report_t* report)
{
  // Check if advertising contain BleUart service
  if ( Bluefruit.Scanner.checkReportForService(report, clientUart) )
  {
    // Serial.print("BLE UART service detected. Connecting ... ");

    // Connect to device with bleuart service in advertising
    Bluefruit.Central.connect(report);
  }else
  {      
    // For Softdevice v6: after received a report, scanner will be paused
    // We need to call Scanner resume() to continue scanning
    Bluefruit.Scanner.resume();
  }
}

/**
 * Callback invoked when an connection is established
 * @param conn_handle
 */
void connect_callback(uint16_t conn_handle)
{
  // Serial.println("Connected");

  // Serial.print("Discovering BLE Uart Service ... ");
  if ( clientUart.discover(conn_handle) )
  {
    // Serial.println("Found it");

    // Serial.println("Enable TXD's notify");
    clientUart.enableTXD();

    // Serial.println("Ready to receive from peripheral");
  }else
  {
    // Serial.println("Found NONE");
    
    // disconnect since we couldn't find bleuart service
    Bluefruit.disconnect(conn_handle);
  }  

  if (clientUart.available()){
    clientUart.flush();
  }
}

/**
 * Callback invoked when a connection is dropped
 * @param conn_handle
 * @param reason is a BLE_HCI_STATUS_CODE which can be found in ble_hci.h
 */
void disconnect_callback(uint16_t conn_handle, uint8_t reason)
{
  (void) conn_handle;
  (void) reason;
  
  // Serial.print("Disconnected, reason = 0x"); Serial.println(reason, HEX);
}

/**
 * Callback invoked when uart received data
 * @param uart_svc Reference object to the service where the data 
 * arrived. In this example it is clientUart
 */ 
void bleuart_rx_callback(BLEClientUart& uart_svc)
{

  if(uart_svc.available()){
    uart_svc.read(ble_buffer,244);
    uart_svc.flush(); // empty rx fifo
    Serial.print(ble_buffer);
    memset(ble_buffer, 0, 244);
  }

  

}


void loop()
{
  delay(5000);
}
